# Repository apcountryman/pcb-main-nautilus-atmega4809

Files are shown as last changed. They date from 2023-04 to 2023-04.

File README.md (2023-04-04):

# pcb-main-nautilus-atmega4809



A Microchip ATmega4809 based mainboard PCB that uses a form factor similar to the Arduino
Uno Rev3.

## Obtaining the Source Code
HTTPS:
```shell
git clone --recurse-submodules https://github.com/apcountryman/pcb-main-nautilus-atmega4809.git
```
SSH:
```shell
git clone --recurse-submodules git@github.com:apcountryman/pcb-main-nautilus-atmega4809.git
```

## Board Setup
The board setup uses OSH Park's 4 layer board stackup and design rules which can be found
at https://docs.oshpark.com/services/ and https://docs.oshpark.com/services/four-layer/.

## Usage
This repository's Git `pre-commit` hook script is the simplest way to test this project
during development.
See the `pre-commit` script's help text for usage details.
```shell
./git/hooks/pre-commit --help
```

Additional checks, such as static analysis, are performed by this project's GitHub Actions
CI workflow.

## Versioning
`pcb-main-nautilus-atmega4809` uses [Semantic Versioning
2.0.0](https://semver.org/spec/v2.0.0.html).
Version tags are prefixed with a `v`.

## Workflow
`pcb-main-nautilus-atmega4809` uses the [GitHub
flow](https://guides.github.com/introduction/flow/) workflow.

## Git Hooks
To install this repository's Git hooks, execute the `install` script located in the
`git/hooks` directory.
See the `install` script's help text for usage details.
```shell
./git/hooks/install --help
```

## Code of Conduct
`pcb-main-nautilus-atmega4809` has adopted the Contributor Covenant 2.0 code of conduct.
For more information, [see the `CODE_OF_CONDUCT.md` file in this
repository](CODE_OF_CONDUCT.md).

## Contributing
If you are interested in contributing to `pcb-main-nautilus-atmega4809`, please [read the
`CONTRIBUTING.md` file in this repository](CONTRIBUTING.md).

## Authors
- Andrew Countryman

## License
For licensing information, [see the `LICENSE.md` file in this repository](LICENSE.md).

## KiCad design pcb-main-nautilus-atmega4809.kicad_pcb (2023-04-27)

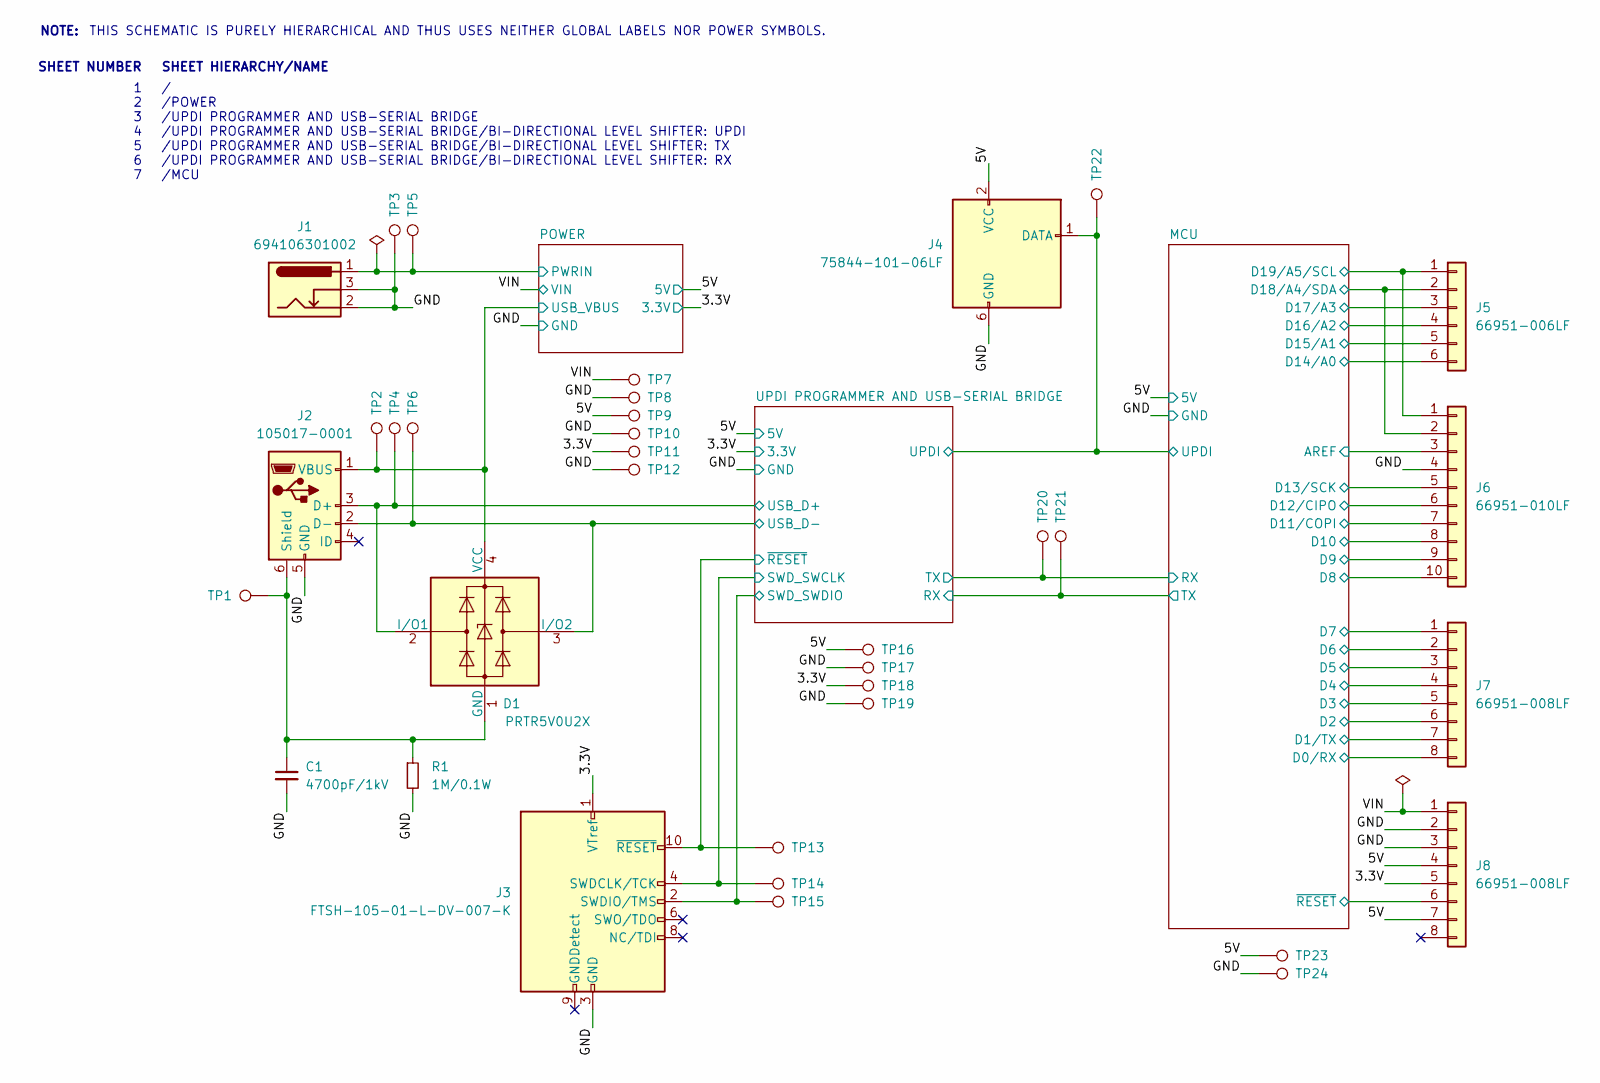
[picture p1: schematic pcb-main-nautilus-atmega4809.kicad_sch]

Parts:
C1: 4700pF/1kV; C_0805_2012Metric_Pad1.18x1.45mm_HandSolder; Manufacturer Part Number C0805V472KDRAC; Digi-Key Part Number 399-C0805V472KDRAC7800CT-ND
D1: PRTR5V0U2X; SOT-143; Manufacturer Part Number PRTR5V0U2X; Digi-Key Part Number 1727-3884-1-ND
J1: 694106301002; BarrelJack_Wuerth_6941xx301002; Manufacturer Part Number 694106301002; Digi-Key Part Number 732-5930-ND
J2: 105017-0001; USB_Micro-B_Molex-105017-0001; Manufacturer Part Number 105017-0001; Digi-Key Part Number WM1399CT-ND
J3: FTSH-105-01-L-DV-007-K; PinHeader_2x05_P1.27mm_Vertical_SMD; Manufacturer Part Number FTSH-105-01-L-DV-007-K; Digi-Key Part Number SAM9438-ND
J4: 75844-101-06LF; PinHeader_2x03_P2.54mm_Vertical; Manufacturer Part Number 75844-101-06LF; Digi-Key Part Number 609-75844-101-06LF-ND
J5: 66951-006LF; PinHeader_1x06_P2.54mm_Vertical; Manufacturer Part Number 66951-006LF; Digi-Key Part Number 609-2236-ND
J6: 66951-010LF; PinHeader_1x10_P2.54mm_Vertical; Manufacturer Part Number 66951-010LF; Digi-Key Part Number 609-2240-ND
J7, J8: 66951-008LF; PinHeader_1x08_P2.54mm_Vertical; Manufacturer Part Number 66951-008LF; Digi-Key Part Number 609-2238-ND
R1: 1M/0.1W; R_0603_1608Metric_Pad0.98x0.95mm_HandSolder; Manufacturer Part Number ERJ-3EKF1004; Digi-Key Part Number P1.00MHCT-ND
TP1, TP2, TP3, TP4, TP5, TP6, TP7, TP8, TP9, TP10, TP11, TP12, TP13, TP14, TP15, TP16, TP17, TP18, TP19, TP20, TP21, TP22, TP23, TP24: TestPoint; TestPoint_Pad_D1.0mm

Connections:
/3.3V: J3.1 (VTref), J8.5, TP11.1, TP18.1; also elsewhere on the board
/5V: J4.2 (VCC), J8.4, J8.7, TP9.1, TP16.1, TP23.1; also elsewhere on the board
/GND: C1.2, J1.2, J1.3, J2.5 (GND), J3.3 (GND), J3.5 (GND), J4.6 (GND), J6.4, J8.2, J8.3, R1.2, TP3.1, TP8.1, TP10.1, TP12.1, TP17.1, TP19.1, TP24.1; also elsewhere on the board
/MCU/AREF: J6.3; also elsewhere on the board
/MCU/D0/RX: J7.8; also elsewhere on the board
/MCU/D1/TX: J7.7; also elsewhere on the board
/MCU/D2: J7.6; also elsewhere on the board
/MCU/D3: J7.5; also elsewhere on the board
/MCU/D4: J7.4; also elsewhere on the board
/MCU/D5: J7.3; also elsewhere on the board
/MCU/D6: J7.2; also elsewhere on the board
/MCU/D7: J7.1; also elsewhere on the board
/MCU/D8: J6.10; also elsewhere on the board
/MCU/D9: J6.9; also elsewhere on the board
/MCU/D10: J6.8; also elsewhere on the board
/MCU/D11/COPI: J6.7; also elsewhere on the board
/MCU/D12/CIPO: J6.6; also elsewhere on the board
/MCU/D13/SCK: J6.5; also elsewhere on the board
/MCU/D14/A0: J5.6; also elsewhere on the board
/MCU/D15/A1: J5.5; also elsewhere on the board
/MCU/D16/A2: J5.4; also elsewhere on the board
/MCU/D17/A3: J5.3; also elsewhere on the board
/MCU/D18/A4/SDA: J5.2, J6.2; also elsewhere on the board
/MCU/D19/A5/SCL: J5.1, J6.1; also elsewhere on the board
/MCU/RX: TP20.1; also elsewhere on the board
/MCU/TX: TP21.1; also elsewhere on the board
/MCU/UPDI: J4.1 (DATA), TP22.1; also elsewhere on the board
/MCU/~RESET: J8.6; also elsewhere on the board
/POWER/PWRIN: J1.1, TP5.1; also elsewhere on the board
/POWER/USB_VBUS: D1.4 (VCC), J2.1 (VBUS), TP2.1; also elsewhere on the board
/UPDI PROGRAMMER AND USB-SERIAL BRIDGE/SWD_SWCLK: J3.4 (SWDCLK/TCK), TP14.1; also elsewhere on the board
/UPDI PROGRAMMER AND USB-SERIAL BRIDGE/SWD_SWDIO: J3.2 (SWDIO/TMS), TP15.1; also elsewhere on the board
/UPDI PROGRAMMER AND USB-SERIAL BRIDGE/USB_D+: D1.2 (I/O1), J2.3 (D+), TP4.1; also elsewhere on the board
/UPDI PROGRAMMER AND USB-SERIAL BRIDGE/USB_D-: D1.3 (I/O2), J2.2 (D-), TP6.1; also elsewhere on the board
/UPDI PROGRAMMER AND USB-SERIAL BRIDGE/~RESET: J3.10 (~RESET), TP13.1; also elsewhere on the board
/VIN: J8.1, TP7.1; also elsewhere on the board
unnamed: C1.1, D1.1 (GND), J2.6 (Shield), R1.1, TP1.1

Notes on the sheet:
/ /POWER /UPDI PROGRAMMER AND USB-SERIAL BRIDGE /UPDI PROGRAMMER AND USB-SERIAL BRIDGE/BI-DIRECTIONAL LEVEL SHIFTER: UPDI /UPDI PROGRAMMER AND USB-SERIAL BRIDGE/BI-DIRECTIONAL LEVEL SHIFTER: TX /UPDI PROGRAMMER AND USB-SERIAL BRIDGE/BI-DIRECTIONAL LEVEL SHIFTER: RX /MCU
SHEET HIERARCHY/NAME
1 2 3 4 5 6 7
THIS SCHEMATIC IS PURELY HIERARCHICAL AND THUS USES NEITHER GLOBAL LABELS NOR POWER SYMBOLS.
SHEET NUMBER
NOTE:

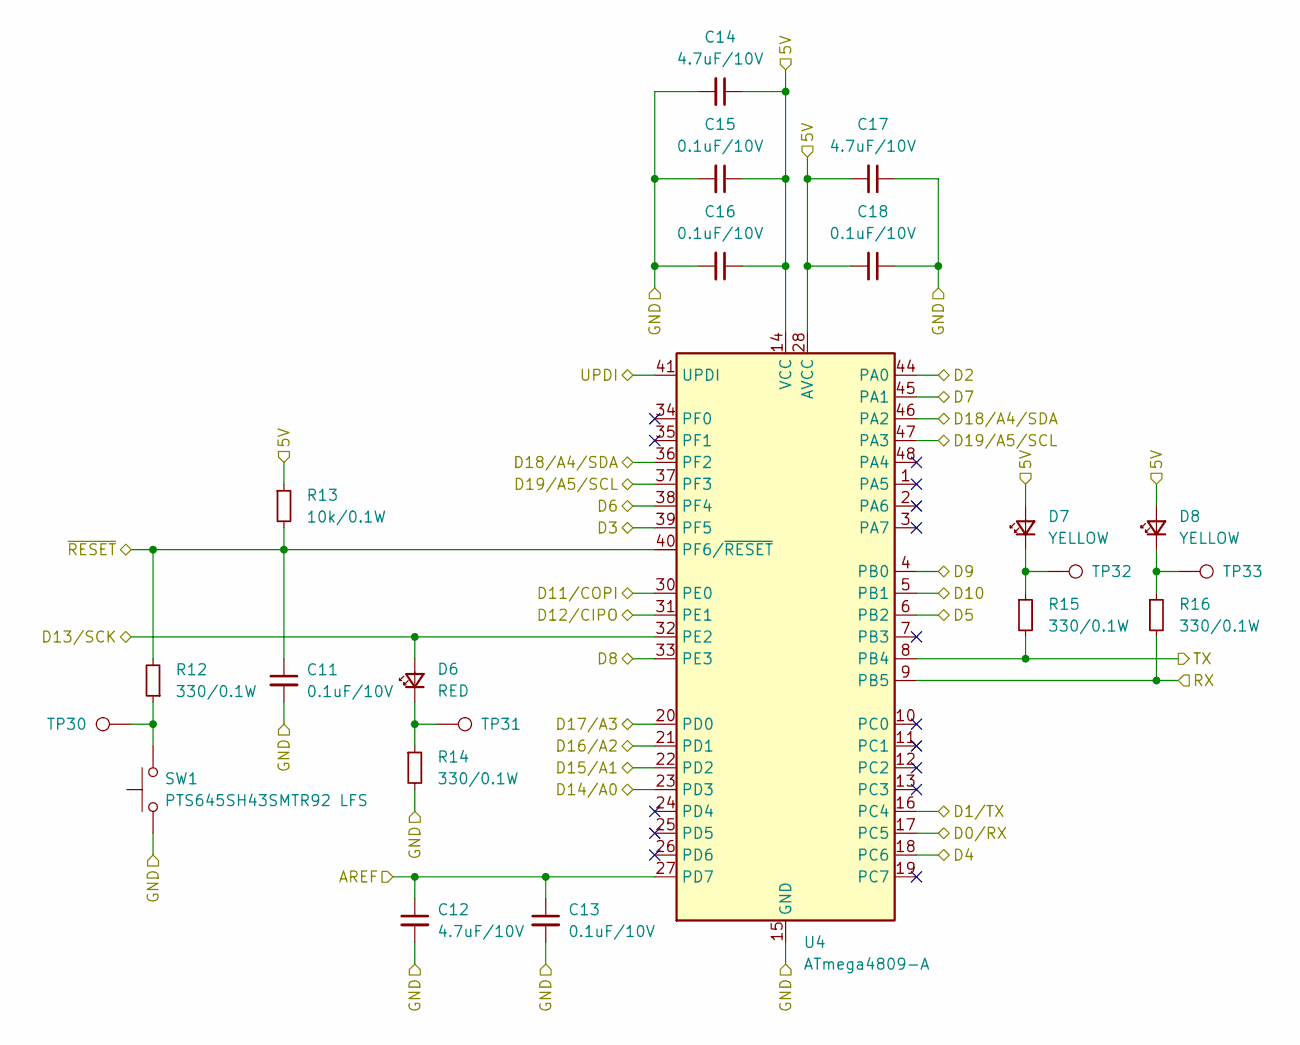
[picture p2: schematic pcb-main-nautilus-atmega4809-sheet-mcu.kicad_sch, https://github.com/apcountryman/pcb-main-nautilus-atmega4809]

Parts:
C11, C13, C15, C16, C18: 0.1uF/10V; C_0603_1608Metric_Pad1.08x0.95mm_HandSolder; Manufacturer Part Number C0603C104M8RAC; Digi-Key Part Number 399-C0603C104M8RAC7867CT-ND
C12, C14, C17: 4.7uF/10V; C_0603_1608Metric_Pad1.08x0.95mm_HandSolder; Manufacturer Part Number C0603C475M8PAC; Digi-Key Part Number 399-C0603C475M8PAC7867CT-ND
D6: RED; LED_0603_1608Metric_Pad1.05x0.95mm_HandSolder; Manufacturer Part Number LTST-C190KRKT; Digi-Key Part Number 160-1436-1-ND
D7, D8: YELLOW; LED_0603_1608Metric_Pad1.05x0.95mm_HandSolder; Manufacturer Part Number LTST-C190KSKT; Digi-Key Part Number 160-1437-1-ND
R12, R14, R15, R16: 330/0.1W; R_0603_1608Metric_Pad0.98x0.95mm_HandSolder; Manufacturer Part Number ERJ-3EKF3300; Digi-Key Part Number P330HCT-ND
R13: 10k/0.1W; R_0603_1608Metric_Pad0.98x0.95mm_HandSolder; Manufacturer Part Number ERJ-3EKF1002; Digi-Key Part Number P10.0KHCT-ND
SW1: PTS645SH43SMTR92 LFS; SW_Push_1P1T_NO_6x6mm_H9.5mm; Manufacturer Part Number PTS645SH43SMTR92 LFS; Digi-Key Part Number CKN11907CT-ND
TP30, TP31, TP32, TP33: TestPoint; TestPoint_Pad_D1.0mm
U4: ATmega4809-A; TQFP-48_7x7mm_P0.5mm; Manufacturer Part Number ATMEGA4809-AU; Digi-Key Part Number 150-ATMEGA4809-AURCT-ND

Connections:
/5V: C14.1, C15.1, C16.1, C17.2, C18.2, D7.2 (A), D8.2 (A), R13.1, U4.14 (VCC), U4.28 (AVCC), U4.42 (VCC); also elsewhere on the board
/GND: C11.2, C12.2, C13.2, C14.2, C15.2, C16.2, C17.1, C18.1, R14.2, SW1.1, U4.15 (GND), U4.29 (GND), U4.43 (GND); also elsewhere on the board
/MCU/AREF: C12.1, C13.1, U4.27 (PD7); also elsewhere on the board
/MCU/D0/RX: U4.17 (PC5); also elsewhere on the board
/MCU/D1/TX: U4.16 (PC4); also elsewhere on the board
/MCU/D2: U4.44 (PA0); also elsewhere on the board
/MCU/D3: U4.39 (PF5); also elsewhere on the board
/MCU/D4: U4.18 (PC6); also elsewhere on the board
/MCU/D5: U4.6 (PB2); also elsewhere on the board
/MCU/D6: U4.38 (PF4); also elsewhere on the board
/MCU/D7: U4.45 (PA1); also elsewhere on the board
/MCU/D8: U4.33 (PE3); also elsewhere on the board
/MCU/D9: U4.4 (PB0); also elsewhere on the board
/MCU/D10: U4.5 (PB1); also elsewhere on the board
/MCU/D11/COPI: U4.30 (PE0); also elsewhere on the board
/MCU/D12/CIPO: U4.31 (PE1); also elsewhere on the board
/MCU/D13/SCK: D6.2 (A), U4.32 (PE2); also elsewhere on the board
/MCU/D14/A0: U4.23 (PD3); also elsewhere on the board
/MCU/D15/A1: U4.22 (PD2); also elsewhere on the board
/MCU/D16/A2: U4.21 (PD1); also elsewhere on the board
/MCU/D17/A3: U4.20 (PD0); also elsewhere on the board
/MCU/D18/A4/SDA: U4.36 (PF2), U4.46 (PA2); also elsewhere on the board
/MCU/D19/A5/SCL: U4.37 (PF3), U4.47 (PA3); also elsewhere on the board
/MCU/RX: R16.2, U4.9 (PB5); also elsewhere on the board
/MCU/TX: R15.2, U4.8 (PB4); also elsewhere on the board
/MCU/UPDI: U4.41 (UPDI); also elsewhere on the board
/MCU/~RESET: C11.1, R12.2, R13.2, U4.40 (PF6/~RESET); also elsewhere on the board
unnamed: D6.1 (K), R14.1, TP31.1
unnamed: D7.1 (K), R15.1, TP32.1
unnamed: D8.1 (K), R16.1, TP33.1
unnamed: R12.1, SW1.2, TP30.1

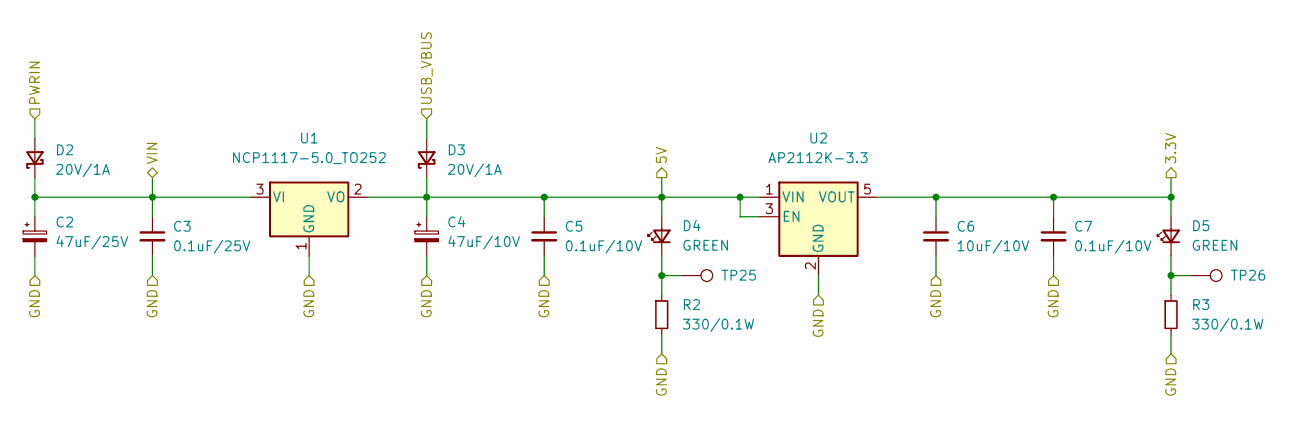
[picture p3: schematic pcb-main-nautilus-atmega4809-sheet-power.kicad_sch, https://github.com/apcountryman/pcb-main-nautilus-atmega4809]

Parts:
C2: 47uF/25V; CP_Elec_6.3x7.7; Manufacturer Part Number EEEHC1E470XP; Digi-Key Part Number PCE3753CT-ND
C3: 0.1uF/25V; C_0603_1608Metric_Pad1.08x0.95mm_HandSolder; Manufacturer Part Number C0603C104M3RAC; Digi-Key Part Number 399-C0603C104M3RAC7867CT-ND
C4: 47uF/10V; CP_Elec_4x5.8; Manufacturer Part Number EEEFN1A470UR; Digi-Key Part Number 10-EEE-FN1A470URCT-ND
C5, C7: 0.1uF/10V; C_0603_1608Metric_Pad1.08x0.95mm_HandSolder; Manufacturer Part Number C0603C104M8RAC; Digi-Key Part Number 399-C0603C104M8RAC7867CT-ND
C6: 10uF/10V; C_0603_1608Metric_Pad1.08x0.95mm_HandSolder; Manufacturer Part Number C0603C106M8PAC; Digi-Key Part Number 399-14945-1-ND
D2, D3: 20V/1A; D_SOD-123F; Manufacturer Part Number MBR120LSF; Digi-Key Part Number MBR120LSFT3GOSCT-ND
D4, D5: GREEN; LED_0603_1608Metric_Pad1.05x0.95mm_HandSolder; Manufacturer Part Number LTST-C190KGKT; Digi-Key Part Number 160-1435-1-ND
R2, R3: 330/0.1W; R_0603_1608Metric_Pad0.98x0.95mm_HandSolder; Manufacturer Part Number ERJ-3EKF3300; Digi-Key Part Number P330HCT-ND
TP25, TP26: TestPoint; TestPoint_Pad_D1.0mm
U1: NCP1117-5.0_TO252; TO-252-2; Manufacturer Part Number NCP1117DT50; Digi-Key Part Number NCP1117DT50RKGOSCT-ND
U2: AP2112K-3.3; SOT-23-5; Manufacturer Part Number AP2112K-3.3TRG1; Digi-Key Part Number AP2112K-3.3TRG1DICT-ND

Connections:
/3.3V: C6.1, C7.1, D5.2 (A), U2.5 (VOUT); also elsewhere on the board
/5V: C4.1, C5.1, D3.1 (K), D4.2 (A), U1.2 (VO), U2.1 (VIN), U2.3 (EN); also elsewhere on the board
/GND: C2.2, C3.2, C4.2, C5.2, C6.2, C7.2, R2.2, R3.2, U1.1 (GND), U2.2 (GND); also elsewhere on the board
/POWER/PWRIN: D2.2 (A); also elsewhere on the board
/POWER/USB_VBUS: D3.2 (A); also elsewhere on the board
/VIN: C2.1, C3.1, D2.1 (K), U1.3 (VI); also elsewhere on the board
unnamed: D4.1 (K), R2.1, TP25.1
unnamed: D5.1 (K), R3.1, TP26.1

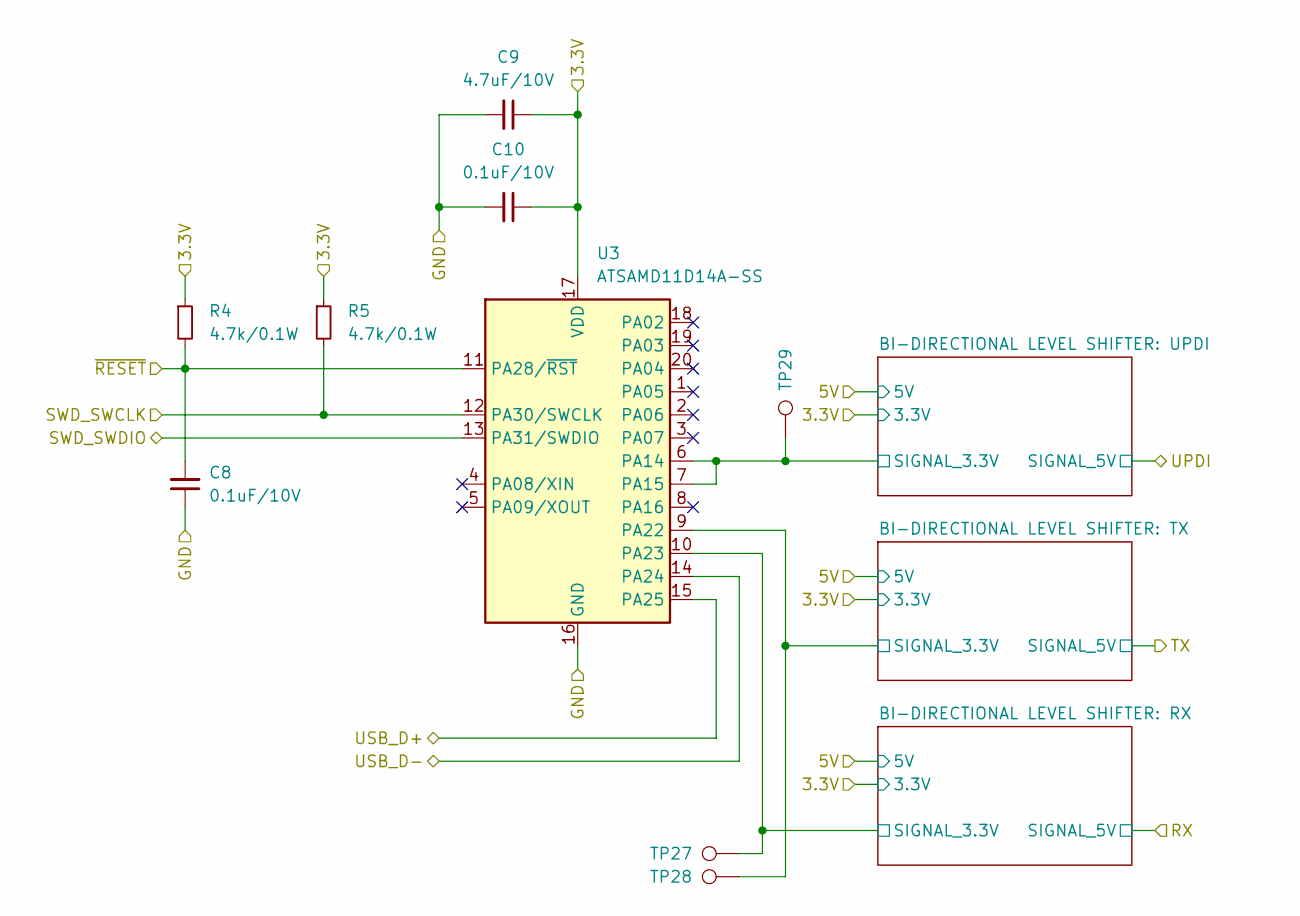
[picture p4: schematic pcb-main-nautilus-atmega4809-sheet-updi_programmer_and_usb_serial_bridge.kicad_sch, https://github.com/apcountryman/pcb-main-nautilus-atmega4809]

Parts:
C8, C10: 0.1uF/10V; C_0603_1608Metric_Pad1.08x0.95mm_HandSolder; Manufacturer Part Number C0603C104M8RAC; Digi-Key Part Number 399-C0603C104M8RAC7867CT-ND
C9: 4.7uF/10V; C_0603_1608Metric_Pad1.08x0.95mm_HandSolder; Manufacturer Part Number C0603C475M8PAC; Digi-Key Part Number 399-C0603C475M8PAC7867CT-ND
R4, R5: 4.7k/0.1W; R_0603_1608Metric_Pad0.98x0.95mm_HandSolder; Manufacturer Part Number ERJ-3EKF4701; Digi-Key Part Number P4.70KHCT-ND
TP27, TP28, TP29: TestPoint; TestPoint_Pad_D1.0mm
U3: ATSAMD11D14A-SS; SOIC-20W_7.5x12.8mm_P1.27mm; Manufacturer Part Number ATSAMD11D14A-SSU; Digi-Key Part Number ATSAMD11D14A-SSUTCT-ND

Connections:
/3.3V: C9.1, C10.1, R4.1, R5.1, U3.17 (VDD); also elsewhere on the board
/GND: C8.1, C9.2, C10.2, U3.16 (GND); also elsewhere on the board
/UPDI PROGRAMMER AND USB-SERIAL BRIDGE/BI-DIRECTIONAL LEVEL SHIFTER: RX/SIGNAL_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: TP27.1, U3.10 (PA23); also elsewhere on the board
/UPDI PROGRAMMER AND USB-SERIAL BRIDGE/BI-DIRECTIONAL LEVEL SHIFTER: TX/SIGNAL_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: TP28.1, U3.9 (PA22); also elsewhere on the board
/UPDI PROGRAMMER AND USB-SERIAL BRIDGE/BI-DIRECTIONAL LEVEL SHIFTER: UPDI/SIGNA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: TP29.1, U3.6 (PA14), U3.7 (PA15); also elsewhere on the board
/UPDI PROGRAMMER AND USB-SERIAL BRIDGE/SWD_SWCLK: R5.2, U3.12 (PA30/SWCLK); also elsewhere on the board
/UPDI PROGRAMMER AND USB-SERIAL BRIDGE/SWD_SWDIO: U3.13 (PA31/SWDIO); also elsewhere on the board
/UPDI PROGRAMMER AND USB-SERIAL BRIDGE/USB_D+: U3.15 (PA25); also elsewhere on the board
/UPDI PROGRAMMER AND USB-SERIAL BRIDGE/USB_D-: U3.14 (PA24); also elsewhere on the board
/UPDI PROGRAMMER AND USB-SERIAL BRIDGE/~RESET: C8.2, R4.2, U3.11 (PA28/~RST); also elsewhere on the board

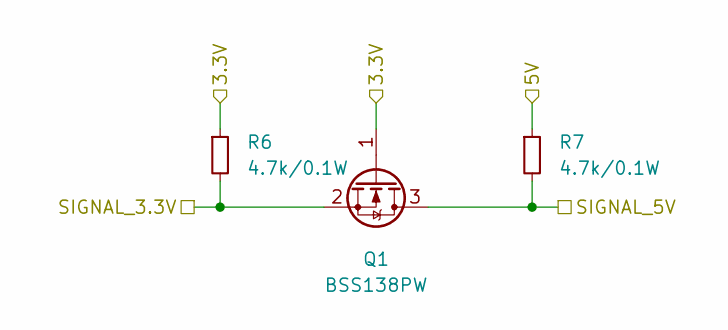
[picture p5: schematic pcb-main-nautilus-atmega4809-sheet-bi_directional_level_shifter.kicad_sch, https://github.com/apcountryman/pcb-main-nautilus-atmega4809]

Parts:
Q1: BSS138PW; SOT-323_SC-70_Handsoldering; Manufacturer Part Number BSS138PW; Digi-Key Part Number 1727-1143-1-ND
R6, R7: 4.7k/0.1W; R_0603_1608Metric_Pad0.98x0.95mm_HandSolder; Manufacturer Part Number ERJ-3EKF4701; Digi-Key Part Number P4.70KHCT-ND

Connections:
/3.3V: Q1.1 (G), R6.1; also elsewhere on the board
/5V: R7.1; also elsewhere on the board
/MCU/UPDI: Q1.3 (D), R7.2; also elsewhere on the board
/UPDI PROGRAMMER AND USB-SERIAL BRIDGE/BI-DIRECTIONAL LEVEL SHIFTER: UPDI/SIGNA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: Q1.2 (S), R6.2; also elsewhere on the board

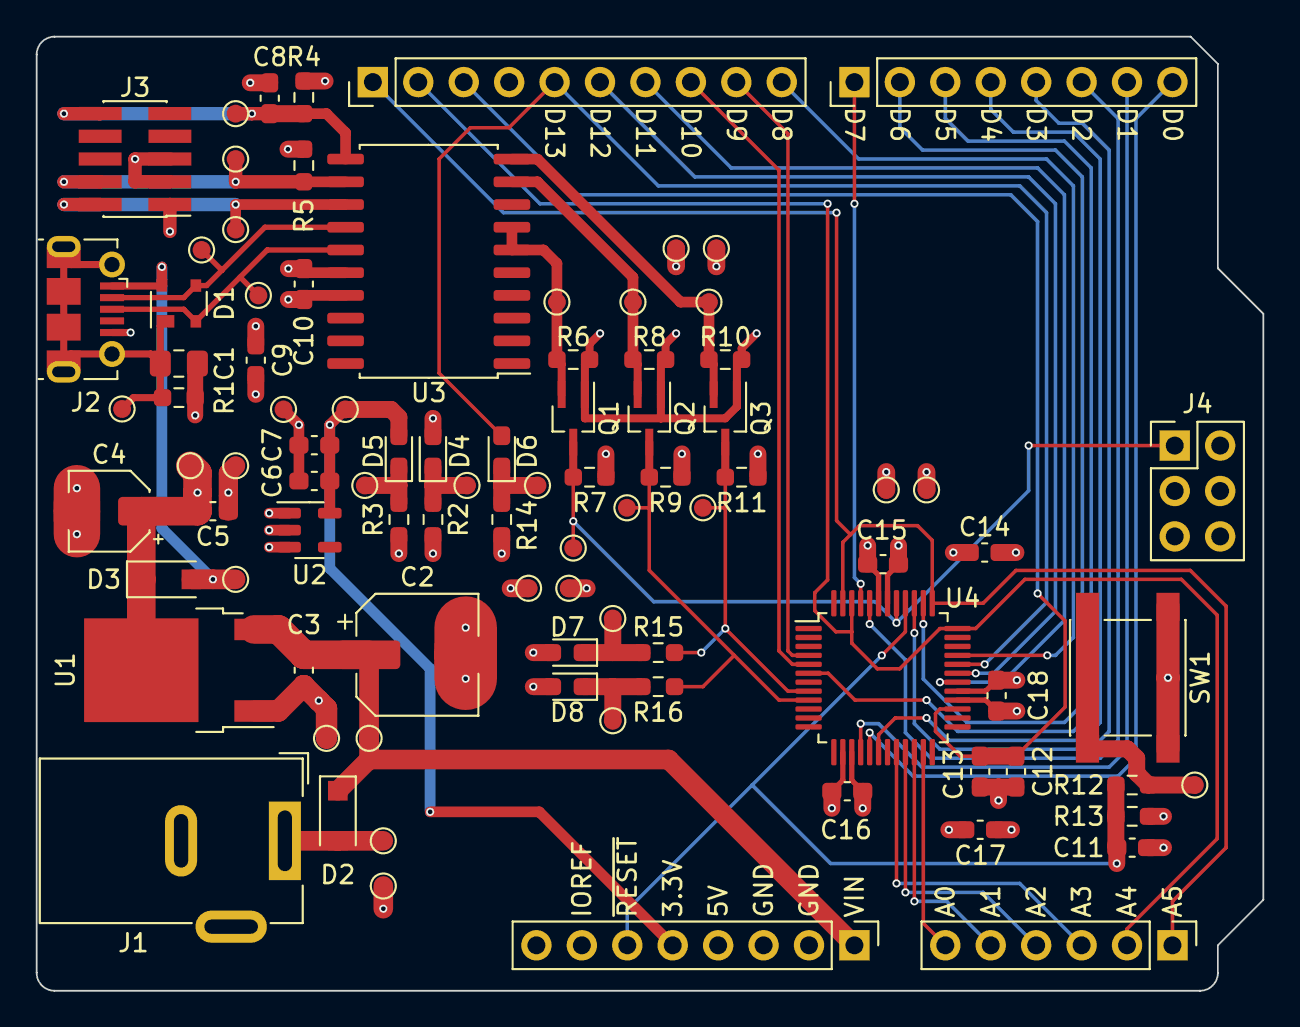
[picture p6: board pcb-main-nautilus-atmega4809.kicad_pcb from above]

Board: 4 copper layers, 68.6 x 53.3 mm, 91 parts (0 on the bottom side), 46 nets.

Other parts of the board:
Q2, Q3: BSS138PW; SOT-323_SC-70_Handsoldering
R8, R9, R10, R11: 4.7k/0.1W; R_0603_1608Metric_Pad0.98x0.95mm_HandSolder

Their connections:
/3.3V: Q2.1 (G), Q3.1 (G), R8.1, R10.1; also elsewhere on the board
/5V: R9.1, R11.1; also elsewhere on the board
/MCU/RX: Q2.3 (D), R9.2; also elsewhere on the board
/MCU/TX: Q3.3 (D), R11.2; also elsewhere on the board
/UPDI PROGRAMMER AND USB-SERIAL BRIDGE/BI-DIRECTIONAL LEVEL SHIFTER: RX/SIGNAL_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: Q3.2 (S), R10.2; also elsewhere on the board
/UPDI PROGRAMMER AND USB-SERIAL BRIDGE/BI-DIRECTIONAL LEVEL SHIFTER: TX/SIGNAL_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: Q2.2 (S), R8.2; also elsewhere on the board

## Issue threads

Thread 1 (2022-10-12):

Add schematic

apcountryman, 2022-10-12:
Add schematic and associated automated checks.
- [x] Add official libraries (ignoring 3D models for now):
    - [x] `official-libraries/kicad-footprints`
    - [x] `official-libraries/kicad-symbols`
- [x] Add utilities:
    - [x] `utilities/KiAuto`
    - [x] `utilities/KiBoM`
    - [x] `utilities/kicad-library-utils`
- [x] Add CI scripts:
    - [x] `ci/check-klc-compliance`
    - [x] `ci/check-electrical-rules-compliance`
    - [x] `ci/generate-schematic-pdf`
    - [x] `ci/generate-bom`
- [x] Add CI jobs:
    - [x] `check-klc-compliance-symbols`
    - [x] `check-klc-compliance-footprints`
    - [x] `check-electrical-rules-compliance`
    - [x] `generate-schematic-pdf`
    - [x] `generate-bom-traditional`
- [x] Add ignore rules to `.gitignore`:
    - [x] `*-backups/`
    - [x] `*-bak`
    - [x] `*.kicad_prl`
    - [x] `*.erc`
    - [x] `bom-*/`
    - [x] `pcb-main-nautilus-atmega4809.xml`
    - [x] `schematic-pdf/`
    - [x] `fp-info-cache`
- [x] Add KiCad files:
    - [x] `pcb-main-nautilus-atmega4809.kicad_pro`
    - [x] `pcb-main-nautilus-atmega4809.kicad_sch`
    - [x] `pcb-main-nautilus-atmega4809-sheet-power.kicad_sch`
    - [x] `pcb-main-nautilus-atmega4809-sheet-updi_programmer_and_usb_serial_bridge.kicad_sch`
    - [x] `pcb-main-nautilus-atmega4809-sheet-bi_directional_level_shifter,kicad_sch`
    - [x] `pcb-main-nautilus-atmega4809-sheet-mcu.kicad_sch`
    - [x] `pcb-main-nautilus-atmega4809.kicad_wks`
    - [x] `sym-lib-table`
    - [x] `fp-lib-table`
- [x] Add KiBoM configuration file (`kibom.ini`)

Closed 2022-12-01.

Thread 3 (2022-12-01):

Add layout

apcountryman, 2022-12-01:
Add layout.
- [x] Add CI scripts
    - [x] `ci/check-design-rules-compliance`
    - [x] `ci/generate-production-files`
- [x] Add interactive BOM support to `ci/generate-bom`
- [x] Add CI jobs
    - [x] `check-design-rules-compliance`
    - [x] `generate-bom-interactive`
    - [x] `generate-production-files`
- [x] Add KiCad files
    - [x] `pcb-main-nautilus-atmega4809.kicad_pcb`

Closed 2023-03-23.

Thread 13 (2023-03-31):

Fix interactive BOM archival

apcountryman, 2023-03-31:
Fix interactive BOM archival (https://github.com/apcountryman/pcb-main-nautilus-atmega4809/actions/runs/4577959488/jobs/8083991097).

Closed 2023-03-31.

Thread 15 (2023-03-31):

Fix production files archival

apcountryman, 2023-03-31:
Fix production files archival (https://github.com/apcountryman/pcb-main-nautilus-atmega4809/actions/runs/4578263863/jobs/8084661511).

Closed 2023-03-31.

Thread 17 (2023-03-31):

Fix release upload

apcountryman, 2023-03-31:
Fix release upload (https://github.com/apcountryman/pcb-main-nautilus-atmega4809/actions/runs/4578379435/jobs/8084916759).

Closed 2023-03-31.

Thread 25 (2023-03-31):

Fix release archive file structure

apcountryman, 2023-03-31:
Fix release archive file structure.
- [x] Do not use absolute paths when archiving files
- [x] Move KiCad files to `pcb-main-nautilus-atmega4809-<version>-hardware-files/kicad` directory
- [x] Move interactive BOM to `pcb-main-nautilus-atmega4809-<version>-hardware-files/bom-interactive` directory
- [x] Move traditional BOM to `pcb-main-nautilus-atmega4809-<version>-hardware-files/bom-traditional` directory
- [x] Move production files to `pcb-main-nautilus-atmega4809-<version>-hardware-files/production-files` directory
- [x] Move schematic PDF to `pcb-main-nautilus-atmega4809-<version>-hardware-files/schematic-pdf` directory

Closed 2023-04-02.

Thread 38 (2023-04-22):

Fix SWD connector footprint

apcountryman, 2023-04-22:
Fix SWD connector footprint.

The footprint is currently `Connector_PinSocket_1.27mm:PinSocket_2x05_P1.27mm_Vertical_SMD` which has pin 1 in the upper right instead of the upper left. The correct footprint is `Connector_PinHeader_1.27mm:PinHeader_2x05_P1.27mm_Vertical_SMD`.

Closed 2023-04-27.

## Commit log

2022-12-01 Add schematic (#2)
    Resolves #1 (Add schematic).
    [pcb-main-nautilus-atmega4809-sheet-bi_directional_level_shifter.kicad_sch, pcb-main-nautilus-atmega4809-sheet-mcu.kicad_sch, pcb-main-nautilus-atmega4809-sheet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]
2023-03-23 Add layout (#4)
    Resolves #3 (Add layout).
    [pcb-main-nautilus-atmega4809-sheet-mcu.kicad_sch, pcb-main-nautilus-atmega4809-sheet-power.kicad_sch, pcb-main-nautilus-atmega4809-sheet-updi_programmer_and_us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]
2023-03-31 Fix interactive BOM archival (#14)
    Resolves #13 (Fix interactive BOM archival).
2023-04-02 Revise CI interactive BOM archive file structure (#30)
    Resolves #26 (Revise CI interactive BOM archive file structure).
2023-04-04 Switch to semantic versioning (#37)
    Resolves #36 (Switch to semantic versioning).
2023-04-27 Fix SWD connector footprint (#39)
    Resolves #38 (Fix SWD connector footprint).
    [pcb-main-nautilus-atmega4809.kicad_pcb, pcb-main-nautilus-atmega4809.kicad_sch]
2023-04-27 Add KiCad worksheet to release hardware files (#41)
    Resolves #40 (Add KiCad worksheet to release hardware files).
